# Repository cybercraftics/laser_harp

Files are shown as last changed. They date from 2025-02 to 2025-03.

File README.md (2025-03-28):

# Laser Harp

## Overview

🎶✨ An Arduino-powered, MIDI-controlled laser harp that transforms a powerful laser, ultrasonic, and light sensors into a futuristic musical instrument. Play music by interrupting laser beams and controlling pitch with hand movements. Includes 3D-printable parts, Arduino code, and schematics.

## Video
Watch the Laser Harp Demo (https://youtu.be/c5HmCTt6hQ4)

## DIY Instructions
https://www.instructables.com/Laser-Harp-2

## Disclaimer

This project is challenging and requires significant fine-tuning, so be prepared for trial and error.

High-powered lasers can cause serious eye injuries and burn skin or surfaces. Please take safety seriously by wearing certified safety glasses and understanding the risks before working with lasers. Take time to educate yourself about proper laser safety and handling techniques.

I am not a professional engineer or mechanic and this project is based on my own personal experience. Always use your best judgment, follow local laws and safety guidelines, and stay aware of any risks involved.

By using these instructions, you agree that I cannot be held responsible for any damage, injuries, or mishaps that may occur. Proceed carefully, do your own research, and take full responsibility for your results.

This guide is for informational and educational purposes only and does not replace professional advice. Consult experts if you have doubts or specific technical questions. You assume all risk and liability for any injuries, damage, or mishaps, and agree to release me from any and all related claims or liabilities.

Thank you for understanding—and have fun creating!

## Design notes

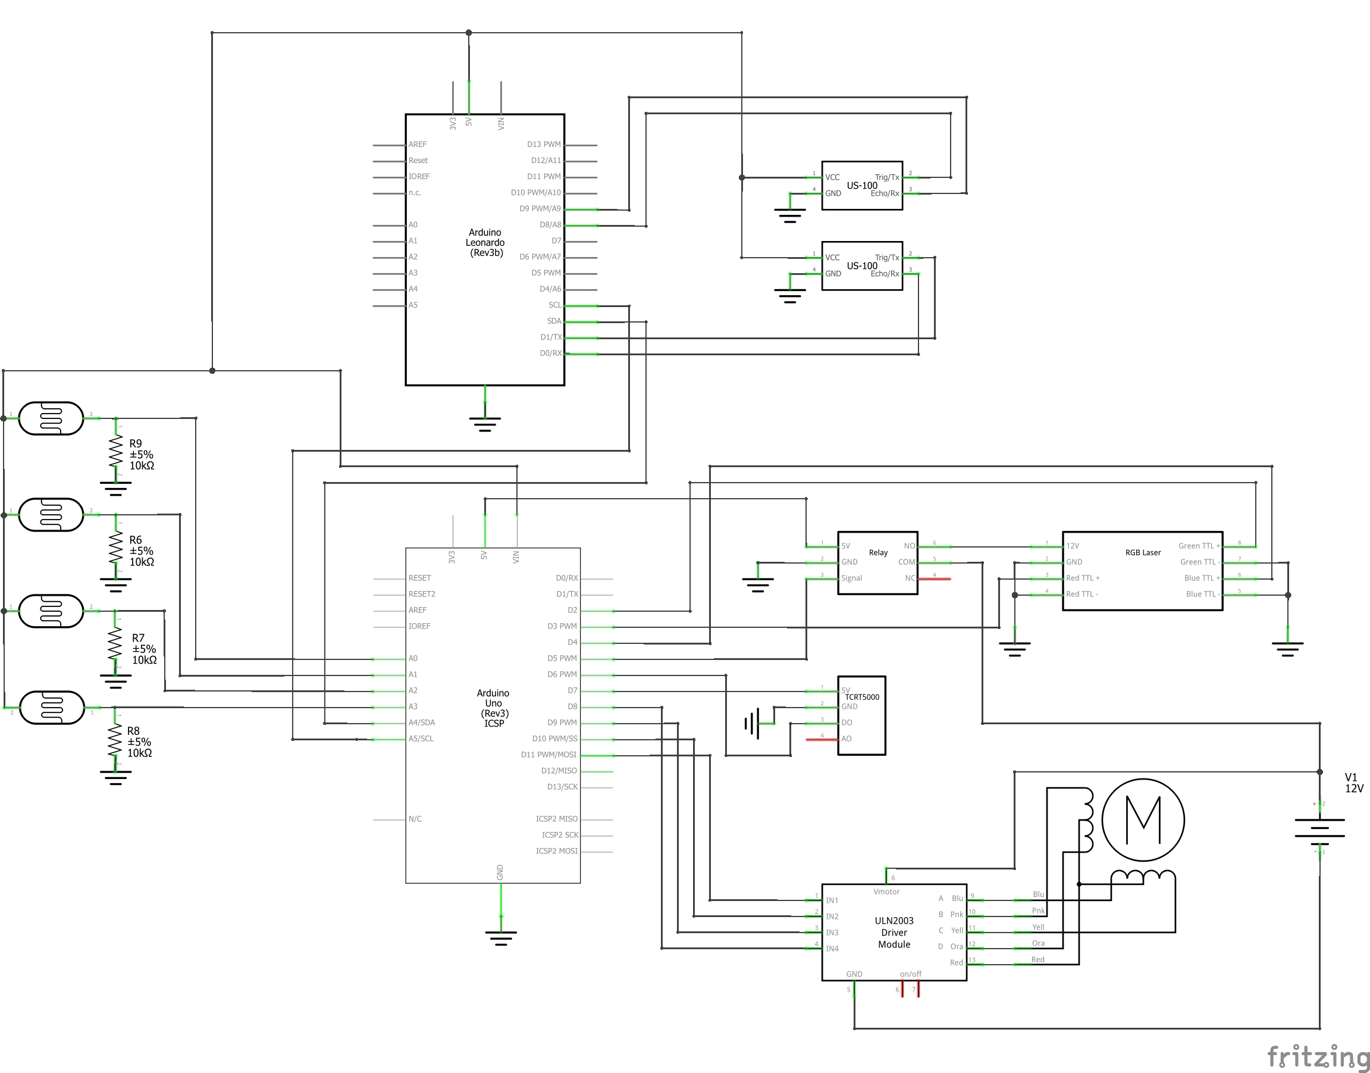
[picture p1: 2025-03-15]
schematics/laser_harp_schem_ULN2003.jpg

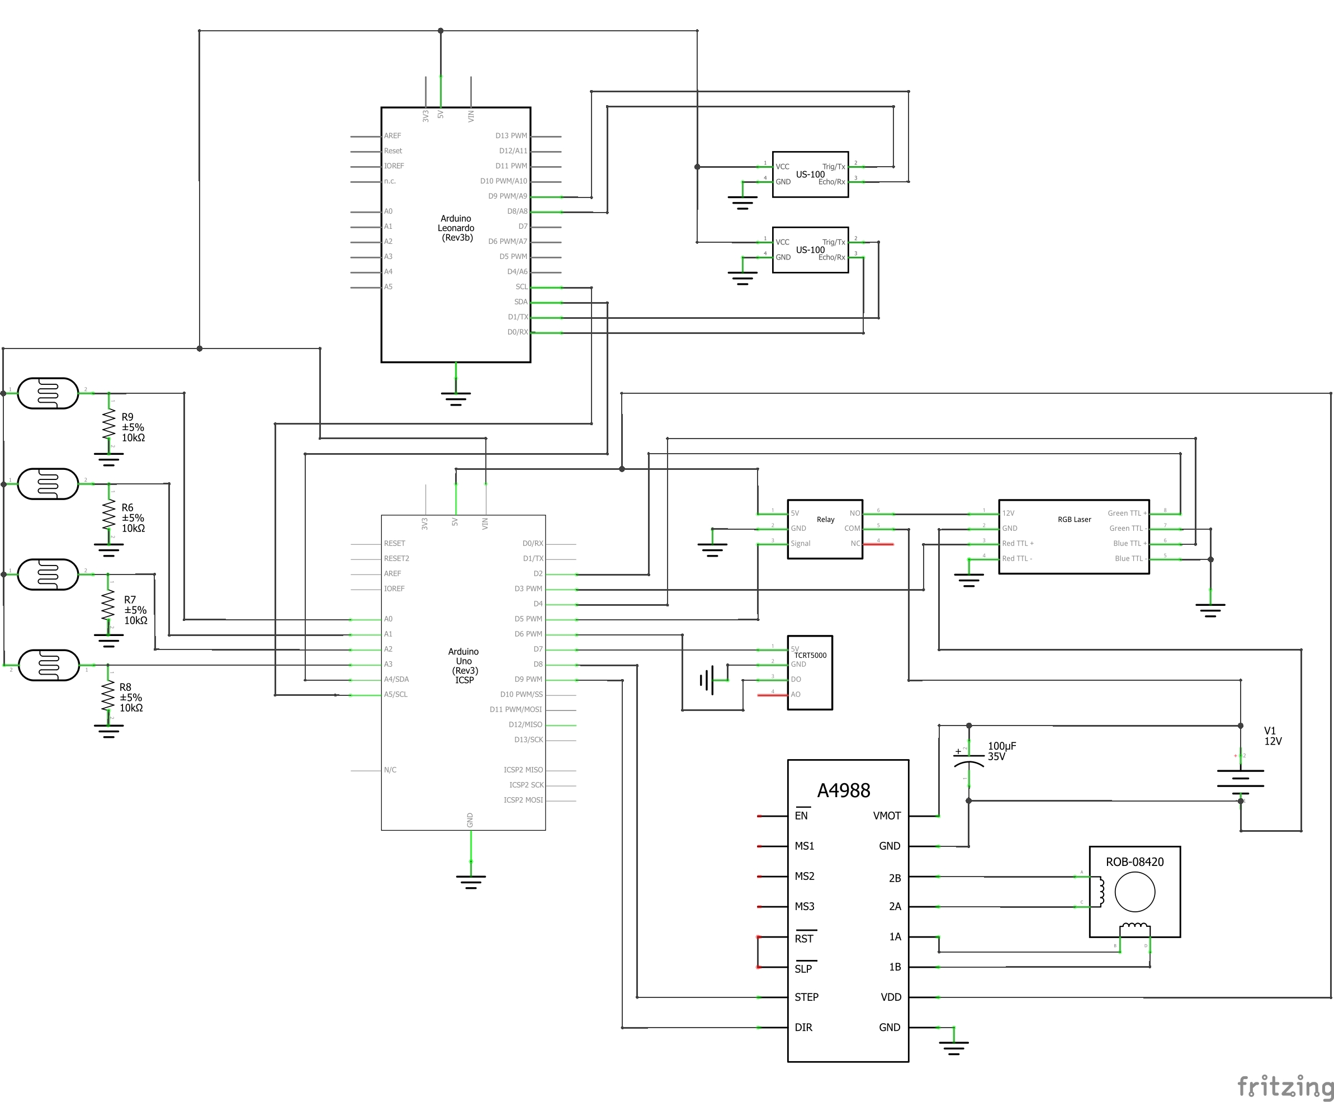
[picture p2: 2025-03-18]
schematics/laser_harp_A4988_schem.jpg

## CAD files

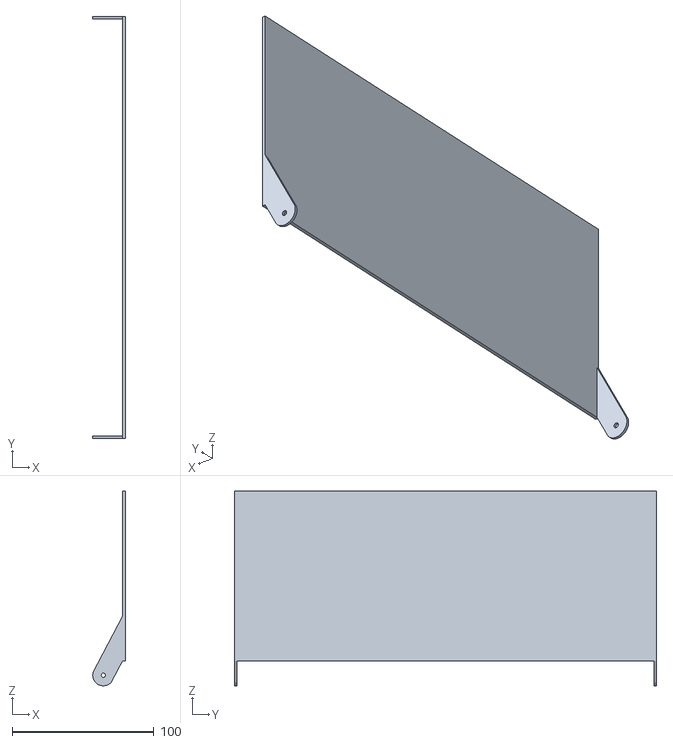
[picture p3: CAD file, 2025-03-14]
3d_printables/Mirror Holder.stl
23.0 x 298.0 x 137.5

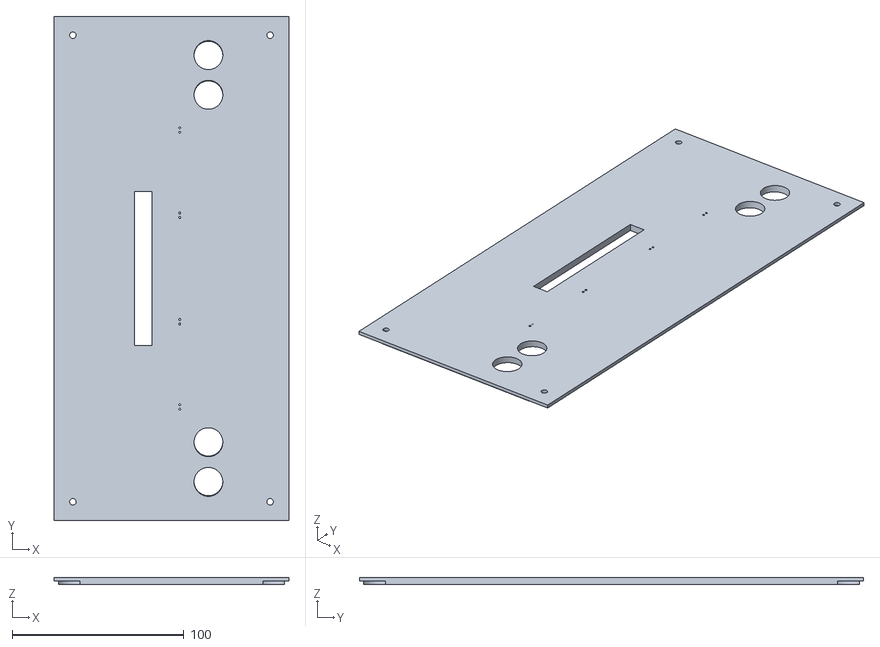
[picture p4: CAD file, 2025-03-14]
3d_printables/Lid.stl
137.0 x 294.0 x 4.00

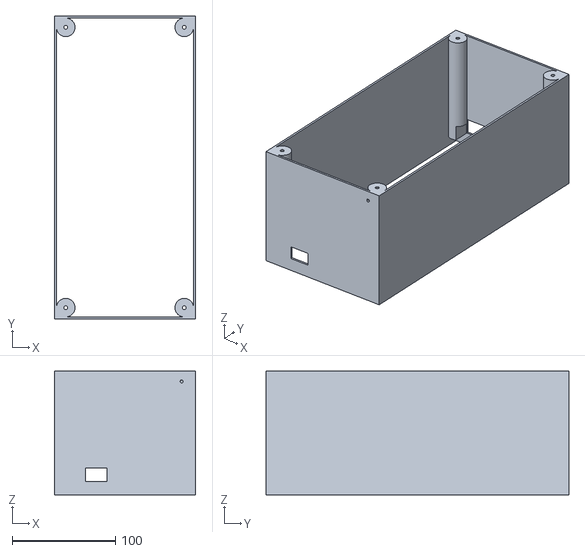
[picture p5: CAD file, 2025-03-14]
3d_printables/Enclosure.stl
137.0 x 294.0 x 120.0

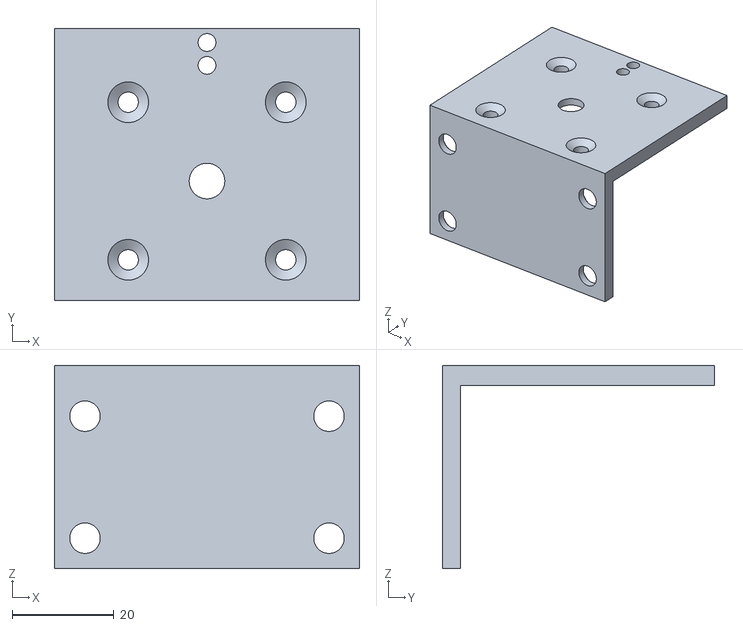
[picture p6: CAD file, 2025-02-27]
3d_printables/Motor Stand.stl
60.0 x 53.5 x 40.0

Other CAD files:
3d_printables/Laser Harp Motor Stand v13.f3d

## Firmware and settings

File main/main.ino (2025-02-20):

#include <Stepper.h>
#include <SoftwareSerial.h>
#include "MIDIUSB.h"

#define GREEN_LASER_PIN  2
#define RED_LASER_PIN    3
#define BLUE_LASER_PIN   4
#define CLOSED_LOOP_VCC_PIN 7
#define CLOSED_LOOP_DO_PIN A5

#define BUZZER_PIN 5

const unsigned int STEPS_PER_REVOLUTION = 200;
const unsigned int STEPPER_SPEED = 220;
const unsigned int STEPPER_HOMING_SPEED = 10;
const unsigned long LASER_ON_DURATION = 150;
const unsigned int NUMBER_OF_STRINGS = 7;
const unsigned int HOME_POSITION = -5;

SoftwareSerial ultrasonicSensor1(8, 9);
Stepper stepper(STEPS_PER_REVOLUTION, 10, 12, 11, 13);

struct SensorState {
  bool playing;
  int  currentPitch;
};

SensorState sensor1State = { false, 0 };
SensorState sensor2State = { false, 0 };

unsigned long lastSensorCheck       = 0;
const unsigned long sensorCheckRate = 200;

unsigned int HighByte = 0;
unsigned int LowByte  = 0;
unsigned int Len      = 0;

void handleMotorAndLaser();
void triggerAndReadUltrasonics();
void processSensorReading(unsigned int distanceMM, SensorState &state, byte channel);
int  mapDistanceToPitch(unsigned int distanceMM, byte sensorIndex);

void noteOn(byte channel, byte pitch, byte velocity);
void noteOff(byte channel, byte pitch, byte velocity);

void setup() {
  Serial.begin(9600);               // debug
  ultrasonicSensor1.begin(9600);    // ultrasonic sensor 1
  Serial1.begin(9600);              // ultrasonic sensor 2

  pinMode(GREEN_LASER_PIN, OUTPUT);
  pinMode(RED_LASER_PIN,   OUTPUT);
  pinMode(BLUE_LASER_PIN,  OUTPUT);
  analogWrite(GREEN_LASER_PIN, 0);
  analogWrite(RED_LASER_PIN,   0);
  analogWrite(BLUE_LASER_PIN,  0);

  pinMode(CLOSED_LOOP_VCC_PIN, OUTPUT);
  pinMode(CLOSED_LOOP_DO_PIN, INPUT);

  homingRoutine();

  stepper.setSpeed(STEPPER_SPEED);
}

void loop() {
  handleMotorAndLaser();

  // unsigned long now = millis();
  // if (now - lastSensorCheck >= sensorCheckRate) {
  //   lastSensorCheck = now;
  //   triggerAndReadUltrasonics();
  // }

  // MidiUSB.flush();
}

void homingRoutine() {
  Serial.println("Homing...");

  digitalWrite(CLOSED_LOOP_VCC_PIN, HIGH);

  stepper.setSpeed(STEPPER_HOMING_SPEED);
  stepper.step(50);
  while (digitalRead(CLOSED_LOOP_DO_PIN) != 0) {
    stepper.step(-1);
  }

  digitalWrite(CLOSED_LOOP_VCC_PIN, LOW);

  stepper.step(HOME_POSITION);

  Serial.println("Homing complete.");
}

void handleMotorAndLaser() {
  for (int i = 0; i < NUMBER_OF_STRINGS; i++) {
    stepper.step(2);
    
    if (i == 3) {
      delayMicroseconds(1000);
    }
    if (i == 4 || i == 5 || i == 6) {
      delayMicroseconds(800);
    }

    analogWrite(GREEN_LASER_PIN, 255);

    delayMicroseconds(LASER_ON_DURATION);

    analogWrite(GREEN_LASER_PIN, 0);
  }
  stepper.step(-NUMBER_OF_STRINGS * 2);
}

// --------------------------------------------------------------------------
//                       Trigger & Read Ultrasonics
// --------------------------------------------------------------------------
void triggerAndReadUltrasonics() {
  // Send "0x55" to each sensor to trigger measurement
  ultrasonicSensor1.write(0x55);   // Sensor1
  Serial1.write(0x55);    // Sensor2

  // Read sensor1 if data is available
  if (ultrasonicSensor1.available() >= 2) {
    HighByte = ultrasonicSensor1.read();
    LowByte  = ultrasonicSensor1.read();
    Len      = (HighByte << 8) + LowByte;
    // Valid range check
    if (Len > 1 && Len <= 1500) {
      processSensorReading(Len, sensor1State, 0); // channel 0
    } else {
      if (sensor1State.playing) {
        noteOff(0, sensor1State.currentPitch, 0x40);
        sensor1State.playing = false;
      }
    }
  }

  // Read sensor2 if data is available
  if (Serial1.available() >= 2) {
    HighByte = Serial1.read();
    LowByte  = Serial1.read();
    Len      = (HighByte << 8) + LowByte;
    if (Len > 1 && Len <= 1500) {
      processSensorReading(Len, sensor2State, 1); // channel 1
    } else {
      if (sensor2State.playing) {
        noteOff(1, sensor2State.currentPitch, 0x40);
        sensor2State.playing = false;
      }
    }
  }
}

void processSensorReading(unsigned int distanceMM, SensorState &state, byte channel) {
  int newPitch = mapDistanceToPitch(distanceMM, channel);

  if (!state.playing) {
    state.playing = true;
    state.currentPitch = newPitch;
    noteOn(channel, newPitch, 100); 
  } else {
    if (newPitch != state.currentPitch) {
      noteOff(channel, state.currentPitch, 0x40);
      state.currentPitch = newPitch;
      noteOn(channel, newPitch, 100);
    }
  }
}

int mapDistanceToPitch(unsigned int distanceMM, byte sensorIndex) {
  int minPitch = 48;  // C2
  int maxPitch = 72;  // C5
  int pitch    = map(distanceMM, 0, 1500, maxPitch, minPitch);

  // Optionally offset one sensor by an octave
  // if (sensorIndex == 1) pitch += 12;

  return constrain(pitch, minPitch, maxPitch);
}

// --------------------------------------------------------------------------
//                       MIDI Helper Functions
// --------------------------------------------------------------------------
void noteOn(byte channel, byte pitch, byte velocity) {
  midiEventPacket_t noteOnPacket = {
    0x09,                    // USB MIDI event (Note On)
    (byte)(0x90 | channel),  // MIDI command (Note On) + channel
    pitch,
    velocity
  };
  MidiUSB.sendMIDI(noteOnPacket);
}

void noteOff(byte channel, byte pitch, byte velocity) {
  midiEventPacket_t noteOffPacket = {
    0x08,                   // USB MIDI event (Note Off)
    (byte)(0x80 | channel), // MIDI command (Note Off) + channel
    pitch,
    velocity
  };
  MidiUSB.sendMIDI(noteOffPacket);
}

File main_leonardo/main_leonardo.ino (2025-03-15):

#include <SoftwareSerial.h>
#include "MIDIUSB.h"
#include <Wire.h>

SoftwareSerial ultrasonicSensor1(8, 9);

struct BeamState {
  bool playing;
  int  currentPitch;
  unsigned long offStartTime;
};

const int NUM_BEAMS = 7;
BeamState beamStates[NUM_BEAMS];

const int baseNotes[NUM_BEAMS] = {36, 38, 40, 41, 43, 45, 47};

const unsigned long OFF_DEBOUNCE_MS = 10; 

unsigned int sensor1Distance = 0;
unsigned int sensor2Distance = 0;

unsigned int lastSensor1Filtered = 0;
unsigned int lastSensor2Filtered = 0;

unsigned int HighByte = 0;
unsigned int LowByte  = 0;
unsigned int Len      = 0;

volatile byte receivedData = 0;

unsigned long lastSensorCheck       = 0;
const unsigned long sensorCheckRate = 20;

int oldOffsetChannel0 = -1; 
int oldOffsetChannel1 = -1;

void triggerAndReadUltrasonics();
int getOctaveOffset(unsigned int distanceMM);
int stabilizeOffset(int newOffset, int &oldOffset);

void noteOn(byte channel, byte pitch, byte velocity);
void noteOff(byte channel, byte pitch, byte velocity);

void receiveEvent(int bytesReceived);

void setup() {
  Serial.begin(9600);
  ultrasonicSensor1.begin(9600); 
  Serial1.begin(9600); 

  for (int i = 0; i < NUM_BEAMS; i++) {
    beamStates[i].playing       = false;
    beamStates[i].currentPitch  = 0;
    beamStates[i].offStartTime  = 0;
  }

  Wire.begin(0x08);
  Wire.onReceive(receiveEvent);
}

void loop() {
  unsigned long now = millis();

  if (now - lastSensorCheck >= sensorCheckRate) {
    lastSensorCheck = now;
    triggerAndReadUltrasonics();
  }

  byte stableData = 0;
  int firstOn = -1;

  for (int i = 0; i < NUM_BEAMS; i++) {
    if (receivedData & (1 << i)) {
      if (firstOn < 0) {
        firstOn = i;
      }
    }
  }

  if (firstOn >= 0) {
    stableData |= (1 << firstOn);
  }

  for (int i = 0; i < NUM_BEAMS; i++) {
    bool beamIsInterrupted = (stableData & (1 << i)) != 0;

    if (beamIsInterrupted) {
      beamStates[i].offStartTime = 0;
      byte channel = (i < 4) ? 0 : 1;
      unsigned int dist = (i < 4) ? sensor1Distance : sensor2Distance;
      int rawOffset = getOctaveOffset(dist);
      int stableOffset = (channel == 0) 
                           ? stabilizeOffset(rawOffset, oldOffsetChannel0)
                           : stabilizeOffset(rawOffset, oldOffsetChannel1);
      int newPitch = baseNotes[i] + stableOffset;

      if (!beamStates[i].playing) {
        if (channel == 0) {
          oldOffsetChannel0 = -1;
        } else {
          oldOffsetChannel1 = -1;
        }

        beamStates[i].playing = true;
        beamStates[i].currentPitch = newPitch;
        noteOn(channel, newPitch, 100);
      } else {
        if (beamStates[i].currentPitch != newPitch) {
          noteOff(channel, beamStates[i].currentPitch, 0x40);
          beamStates[i].currentPitch = newPitch;
          noteOn(channel, newPitch, 100);
        }
      }
    } else {
      if (beamStates[i].playing) {
        if (beamStates[i].offStartTime == 0) {
          beamStates[i].offStartTime = now;
        } else {
          if (now - beamStates[i].offStartTime >= OFF_DEBOUNCE_MS) {
            byte channel = (i < 4) ? 0 : 1;
            noteOff(channel, beamStates[i].currentPitch, 0x40);
            beamStates[i].playing = false;

            if (channel == 0) {
              oldOffsetChannel0 = -1;
            } else {
              oldOffsetChannel1 = -1;
            }
          }
        }
      }
    }
  }

  MidiUSB.flush();
}

void receiveEvent(int bytesReceived) {
  while (Wire.available()) {
    receivedData = Wire.read();
  }
}

void triggerAndReadUltrasonics() {
  ultrasonicSensor1.write(0x55);
  delay(50);

  if (ultrasonicSensor1.available() >= 2) {
    HighByte = ultrasonicSensor1.read();
    LowByte = ultrasonicSensor1.read();
    sensor1Distance = (HighByte << 8) + LowByte;

    if (sensor1Distance < 2 || sensor1Distance > 1800) {
      sensor1Distance = 0;
    }

    if (abs((int)sensor1Distance - (int)lastSensor1Filtered) > 20) {
      sensor1Distance = lastSensor1Filtered;
    } else {
      lastSensor1Filtered = sensor1Distance;
    }
  }

  Serial1.write(0x55);
  delay(50);

  if (Serial1.available() >= 2) {
    HighByte = Serial1.read();
    LowByte = Serial1.read();
    sensor2Distance = (HighByte << 8) + LowByte;

    if (sensor2Distance < 2 || sensor2Distance > 1800) {
      sensor2Distance = 0;
    }

    if (abs((int)sensor2Distance - (int)lastSensor2Filtered) > 20) {
      sensor2Distance = lastSensor2Filtered;
    } else {
      lastSensor2Filtered = sensor2Distance;
    }
  }
}

int getOctaveOffset(unsigned int distanceMM) {
  int offset = map(distanceMM, 0, 1500, 24, 0);
  
  return constrain(offset, 0, 24);
}

int stabilizeOffset(int newOffset, int &oldOffset) {
  if (oldOffset < 0) {
    oldOffset = newOffset;
    return newOffset;
  }

  if (abs(newOffset - oldOffset) <= 1) {
    return oldOffset;
  }

  oldOffset = newOffset;
  return newOffset;
}

void noteOn(byte channel, byte pitch, byte velocity) {
  midiEventPacket_t noteOnPacket = {
    0x09,
    (byte)(0x90 | channel),
    pitch,
    velocity
  };
  MidiUSB.sendMIDI(noteOnPacket);
}

void noteOff(byte channel, byte pitch, byte velocity) {
  midiEventPacket_t noteOffPacket = {
    0x08,
    (byte)(0x80 | channel),
    pitch,
    velocity
  };
  MidiUSB.sendMIDI(noteOffPacket);
}

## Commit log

2024-11-22 Optimal stepper motor settings
2025-01-16 Add some stepper motor experiments
2025-01-22 Change the code to controll an RGB Laser
2025-01-23 Best motor settings
2025-02-13 Add closed loop motor sensor support
2025-02-14 Handle the distance sensor with interrupts
2025-02-14 Split the code into stages
2025-02-18 Add homing routine
2025-02-18 Pretty stable but there is an issue with the tone function that blocks the loop
    [main.ino]
2025-02-20 Steble motor + homing
2025-02-21 Split the logic between the two arduinos
2025-02-26 Add enable laser pin and some fine tunnings
2025-02-27 Improve laser centering
    [Enclosure.stl, Mirror Holder.stl, Motor Stand.stl]
2025-02-28 Add communication between the two Arduinos
    [Lid.stl, Mirror Holder.stl]
2025-03-14 Update the 3D Printables
    [Enclosure.stl, Lid.stl, Mirror Holder.stl]
2025-03-15 Enable the ultrasonic sensors
2025-03-15 Add schematics
    [laser_harp.fzz]
2025-03-15 Generate new schematic image
2025-03-16 Update the schematics
    [laser_harp.fzz, laser_harp_A4988.fzz, laser_harp_ULN2003.fzz]
2025-03-16 Add the fusion source files
    [Laser Harp Motor Stand v13.f3d]
2025-03-18 Add a capacitor to the A4988 driver connection
    [laser_harp_A4988.fzz]
